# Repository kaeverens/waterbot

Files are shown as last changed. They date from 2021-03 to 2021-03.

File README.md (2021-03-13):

# waterbot
a robot for watering plants

I don't know much about gardening, and I am not attentive enough to stick to a watering regime, so this is a project to do it for me.

The idea is that you place the plants you want to water in a line along a track. A small robot then travels along that track, watering each plant.

IMAGE ALT TEXT (http://www.youtube.com/watch?v=uN9o2ADvFOk "first successful watering - click to see the video")

There is a much larger idea behind all of this, but I'll get to that over time. The short-term goal is that plants should each receive a prescribed amount of water every day.

## How to build

these instructions are not yet complete. I'm filling them in as I rebuild things.

1. build a track, using documentation in the "track" directory.
2. build a bot, using documentation in the "bot" directory.
3. connect a pi to the track port, and install the server (to be written)

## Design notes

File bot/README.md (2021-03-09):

There are 3 versions of the bot

v2 is the current version.

v1 was the prototype.

v3 is the next version.

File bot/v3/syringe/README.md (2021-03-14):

The syringe layer can hold up to 6ml of water and push it out on request. It is controlled through i2c.



power usage estimate is 240mA for the 28BYJ-48 motor, and 10mA for the Arduino.

* when the motor is enabled: 1.25W
* when the motor is disabled: 0.05W

the 28BYJ-48 motor has 2038 steps per revolution. the gear reduction from the motor to the syringe-pushing rack is 1/11 * 14/8, and has teeth that are 3.142mm apart, so one step of the motor drives it 0.00969mm, or 0.01mm rounded.

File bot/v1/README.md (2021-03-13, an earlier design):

these files are of the original prototype of the waterbot.

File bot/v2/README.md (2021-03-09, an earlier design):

the bot is made of three separate layers

the bottom layer is the Transport layer. this layer has a motor and wheels, and has switches to identify when the bot hits a track end, or when it passes a marker on the track to identify where the pots are.

the middle layer is for power and control. this layer has an embedded arduino, battery, and battery charger, and it controls the robot.

the top layer is the syringe layer. this layer is used to pick up and drop off water.

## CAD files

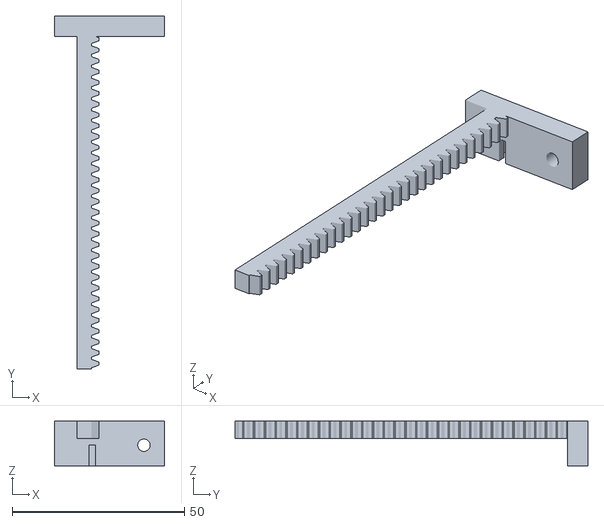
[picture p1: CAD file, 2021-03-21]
bot/v3/syringe/syringe-rack.stl
32.0 x 102.6 x 13.0

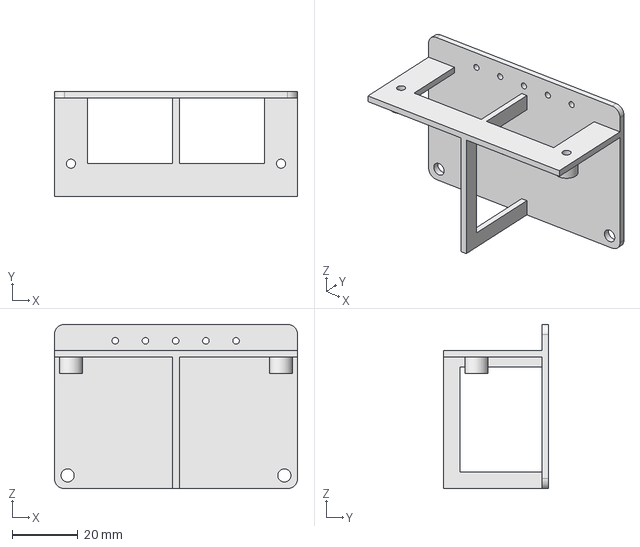
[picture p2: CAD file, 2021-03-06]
dock/dock-wall.FCStd
74.0 x 32.0 x 50.0 mm

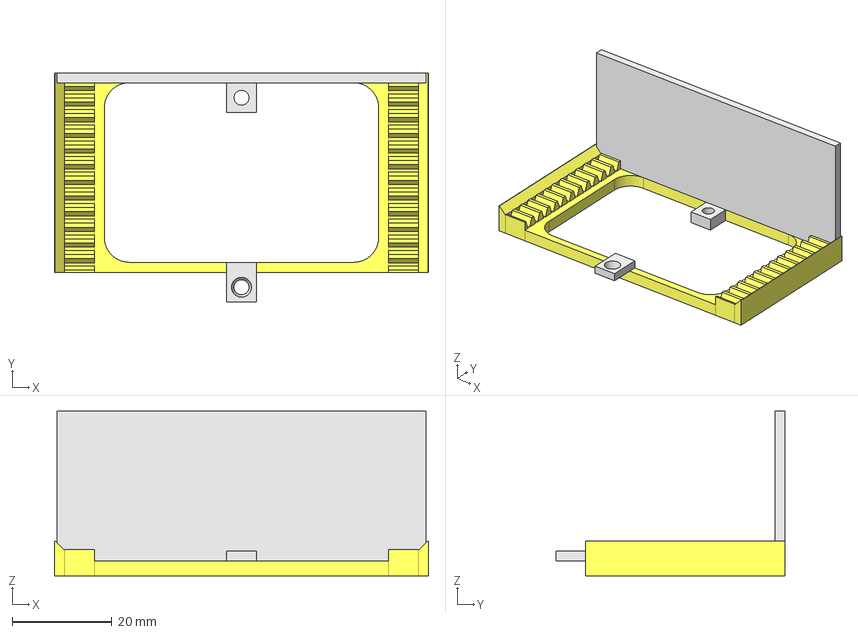
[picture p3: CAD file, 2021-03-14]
tracks/track-end-piece.FCStd
75.0 x 46.0 x 33.0 mm
track

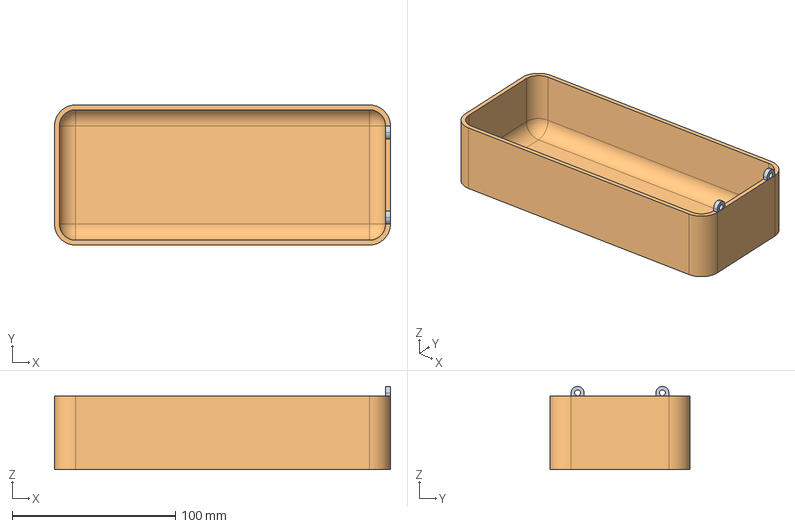
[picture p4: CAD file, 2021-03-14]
trough/trough.FCStd
206.0 x 86.0 x 51.0 mm

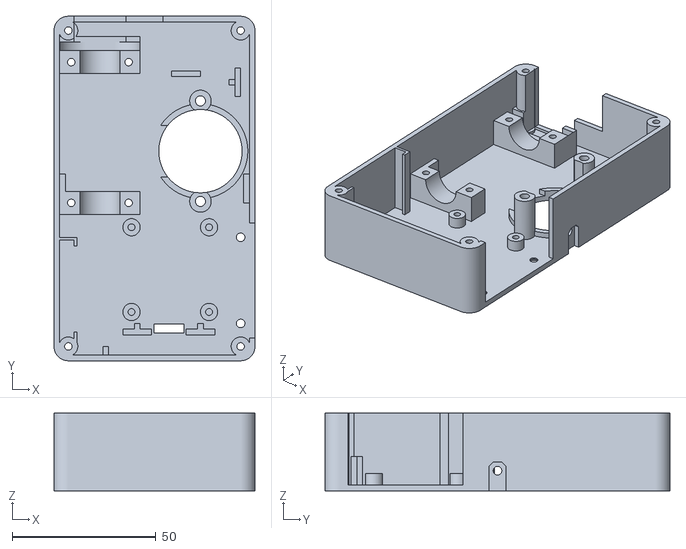
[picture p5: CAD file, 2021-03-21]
bot/v3/syringe/syringe-bottom.stl
70.0 x 120.0 x 27.0

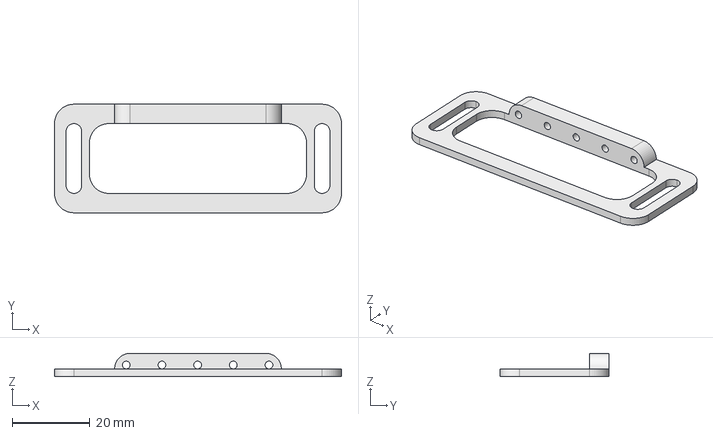
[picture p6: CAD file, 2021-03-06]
dock/dock-pogopin-slider.FCStd
74.0 x 28.0 x 6.00 mm

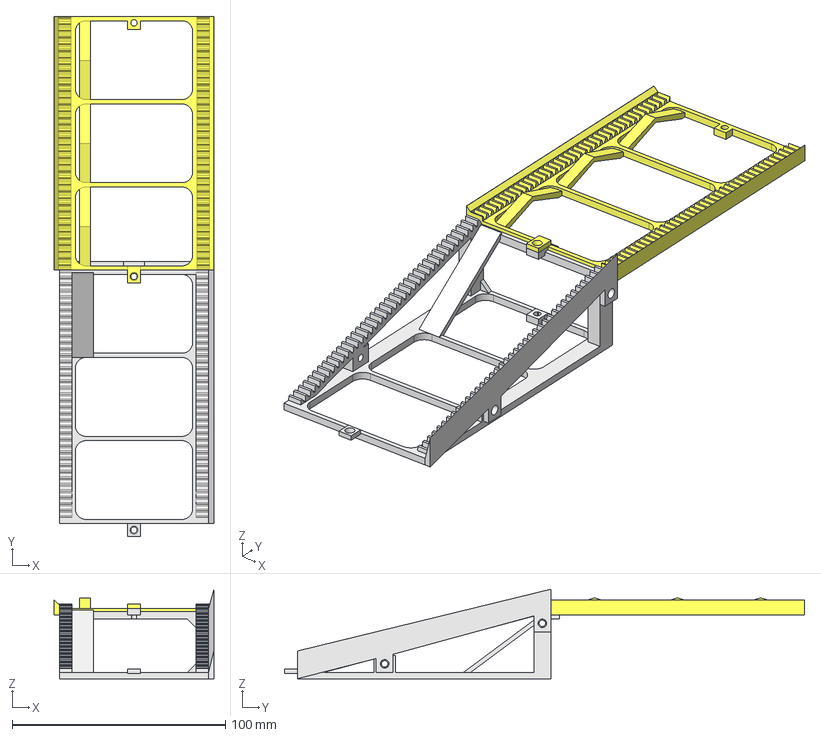
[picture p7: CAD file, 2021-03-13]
tracks/track-riser-30mm.FCStd
75.0 x 244.0 x 42.0 mm
example attached track
3cm riser

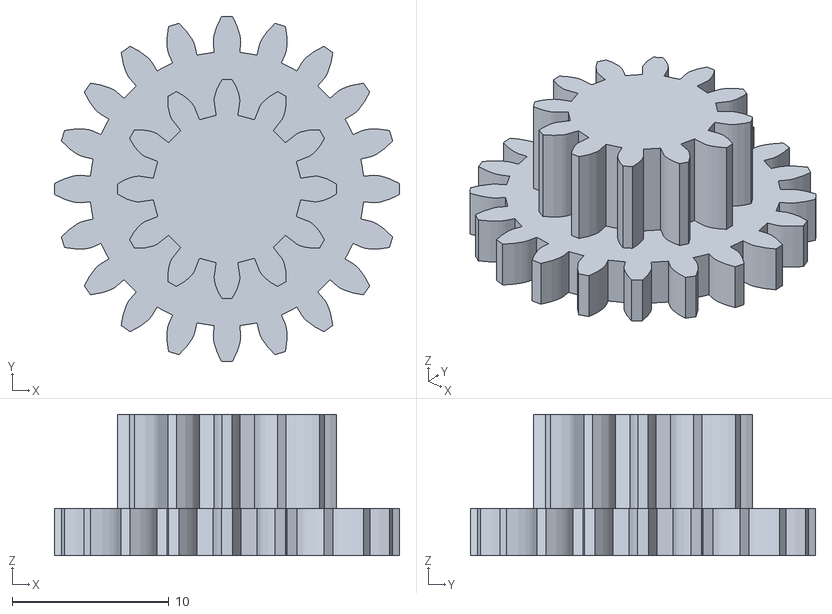
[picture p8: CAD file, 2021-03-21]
bot/v3/syringe/syringe-transmission_gear.stl
22.0 x 22.0 x 9.00

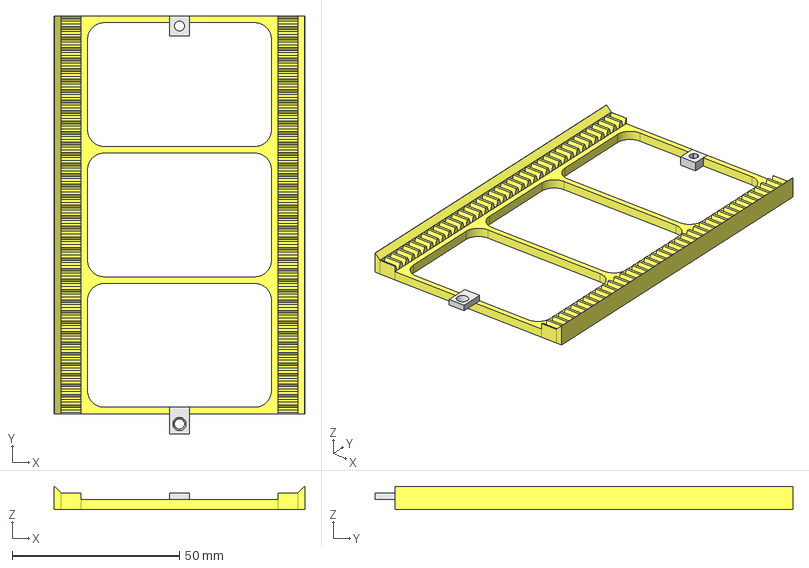
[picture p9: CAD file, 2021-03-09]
tracks/track-120.FCStd
75.0 x 125.0 x 7.00 mm
track

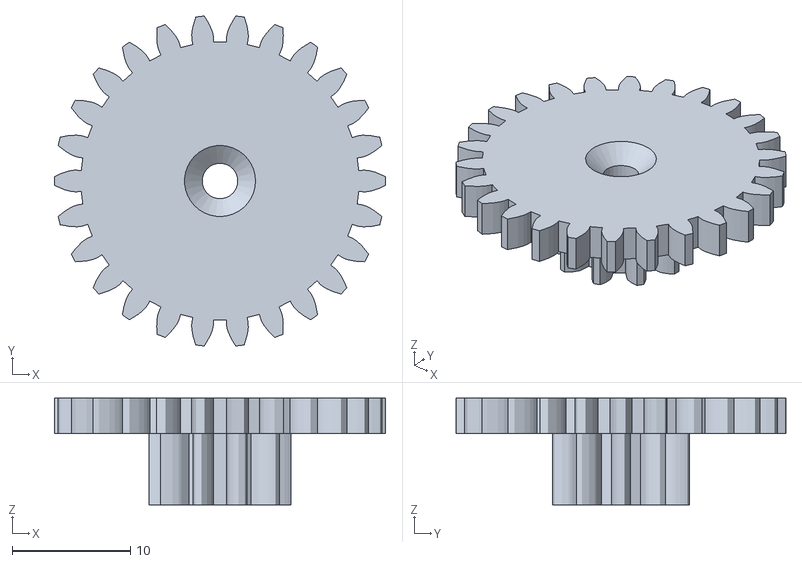
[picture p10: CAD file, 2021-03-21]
bot/v3/syringe/syringe-rack_gear.stl
28.0 x 27.9 x 9.00

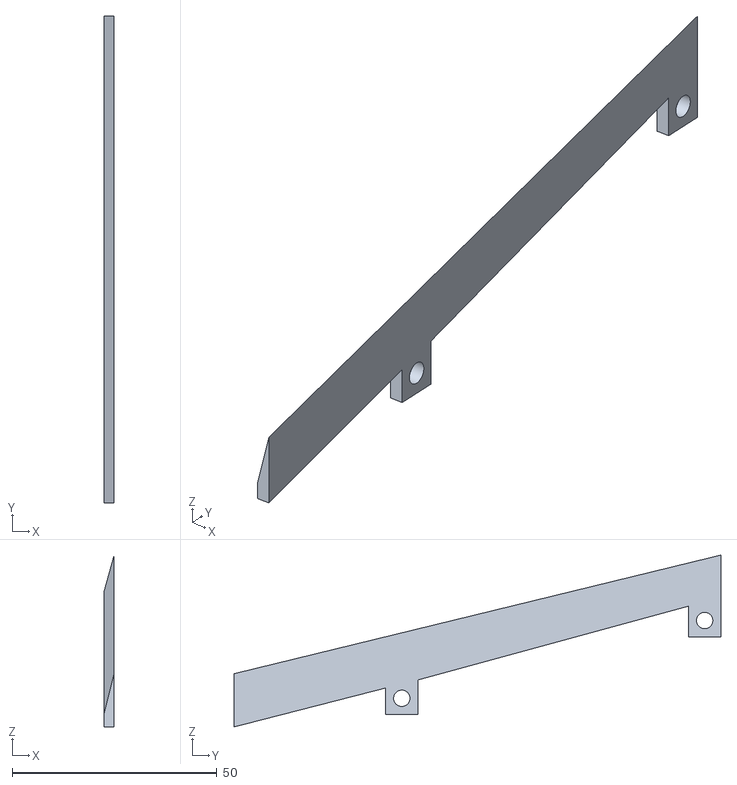
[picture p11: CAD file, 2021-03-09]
tracks/track-riser-30mm-rail.stl
2.50 x 119.0 x 42.0

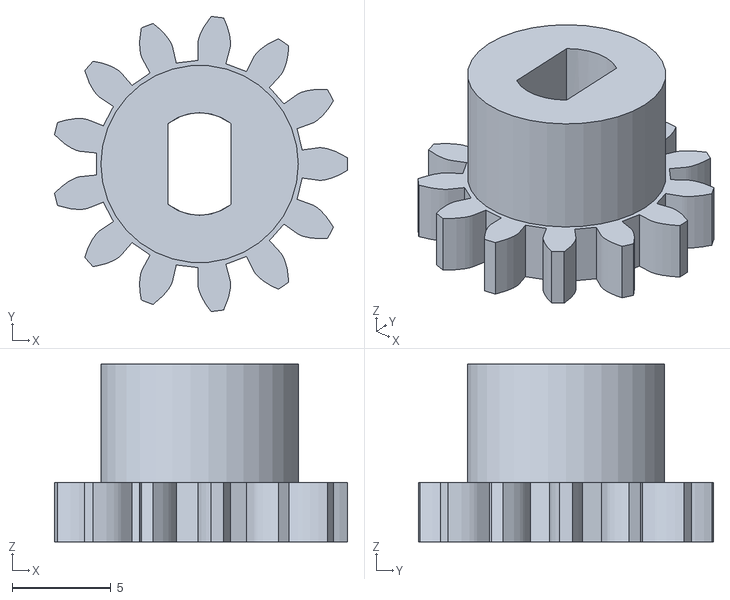
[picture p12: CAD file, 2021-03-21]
bot/v3/syringe/syringe-driver_gear.stl
14.8 x 15.0 x 9.00

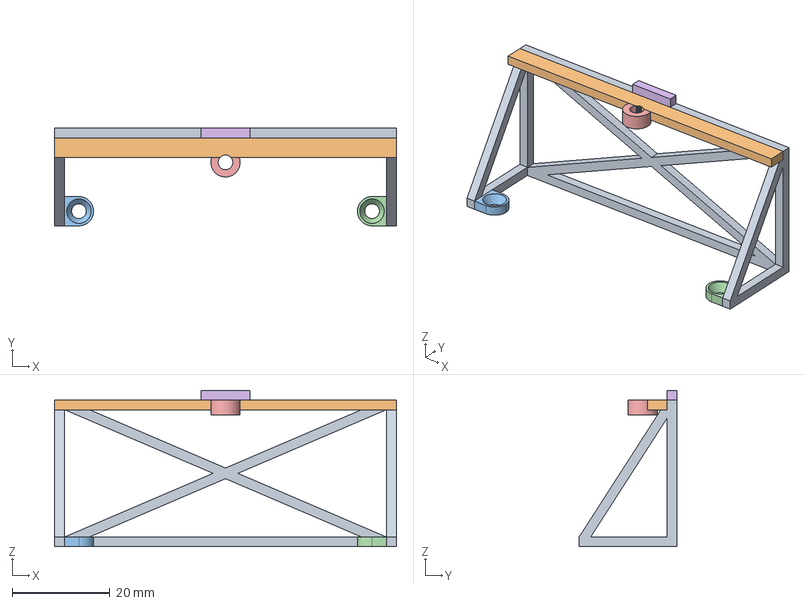
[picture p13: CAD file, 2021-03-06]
tracks/track-truss-30mm.FCStd
70.0 x 20.0 x 32.0 mm

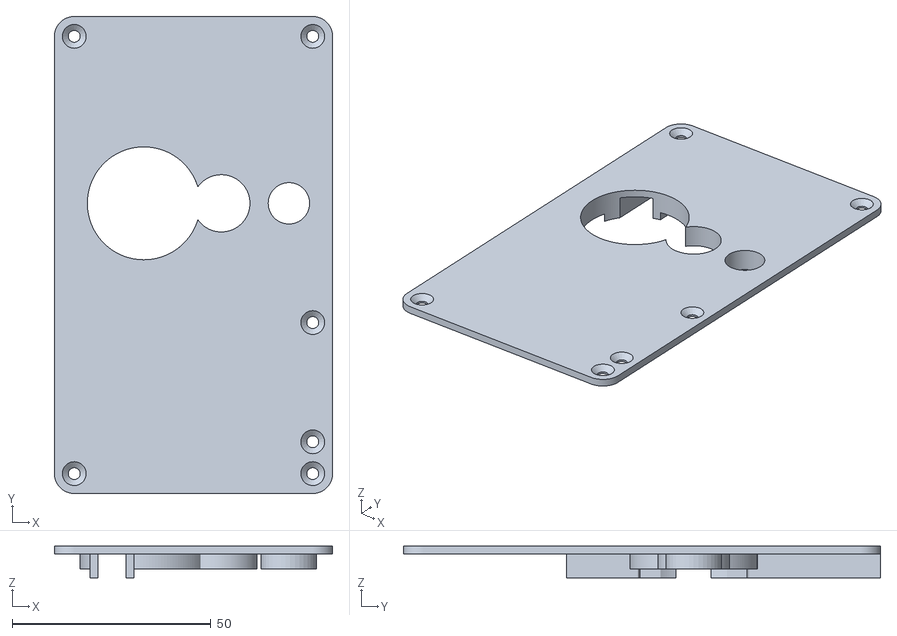
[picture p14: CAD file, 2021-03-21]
bot/v3/syringe/syringe-top.stl
70.0 x 120.0 x 8.00

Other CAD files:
tracks/track-dock.FCStd
bot/v3/syringe/syringe-barrel_strap.stl
tracks/track-120mm.stl
bot/v3/syringe/syringe.FCStd
bot/v1/altogether.FCStd
bot/v1/base-body.FCStd
bot/v1/body-syringe.FCStd
bot/v1/control-boards.FCStd
bot/v1/layer-bumper.FCStd
bot/v1/layer-template.FCStd
bot/v1/motor-axle.FCStd
bot/v1/motor-gear.FCStd
bot/v1/power-block.FCStd
bot/v1/shuttle-top.FCStd
bot/v1/side-switch.FCStd
bot/v1/syringe-mount.FCStd
bot/v1/transmission-gear.FCStd
bot/v1/waterbot.FCStd
bot/v1/wheel-gear.FCStd
bot/v1/wheel.FCStd
bot/v2/power/base.FCStd
bot/v2/power/bot-power-base.stl
bot/v2/syringe/bot-syringe-arm.FCStd
bot/v2/syringe/bot-syringe-arm.stl
bot/v2/syringe/bot-syringe-base.FCStd
bot/v2/syringe/bot-syringe-base.stl
bot/v2/syringe/bot-syringe-mount_body.FCStd
bot/v2/syringe/bot-syringe-mount_body.stl
bot/v2/syringe/bot-syringe-mounts-back.stl
bot/v2/syringe/bot-syringe-mounts-front.stl
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

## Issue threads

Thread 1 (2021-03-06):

syringe arm too long

kaeverens, 2021-03-06:
the syringe arm, when fully extended, pokes out the far side of the robot.

try redesigning the syring holder so the microswitch detects the actual syringe's plunger, not the toothed arm

kaeverens, 2021-03-06:
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

kaeverens, 2021-03-09:
a full redesign of the syringe layer will solve this issue and some others. I'll try redesign it so it's flat, with a tube leading from the end of the syringe out to the side. the tube position should be adjustable.

kaeverens, 2021-03-13:
redesign is well under way.

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

I'm designing this one to work through i2c as the first v3 layer. it won't be compatible with the v2 bot.

kaeverens, 2021-03-14:
closing this, as a rebuild to v3 will solve it. also, I simply moved the track away from the wall, so it's no longer a problem anyway

Closed 2021-03-14.

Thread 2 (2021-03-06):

bottom microswitch gets caught on track joists

kaeverens, 2021-03-06:
the lever of the microswitch dangles too low and gets caught.

two possible solutions

1. remove the lever and hopefully the switch itself can slide over the track lumps
2. redesign tracks so they have a smooth track for the microswitch to roll on where currently it's just a hole

kaeverens, 2021-03-06:
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

kaeverens, 2021-03-06:
simplest solution is the track one.

kaeverens, 2021-03-06:
another possible temporary solution - add some weight to the front of the bot.

more long-term solutions:

1. reduce height of bot in total so centre of balance is lower
2. invert the syringe mechanism so the motor is closer to the centre of the bot horizontally and vertically

I think solution 2 here is the right one.

solution 1 can be worked on when next redesigning the transport layer

kaeverens, 2021-03-06:
after further thinking, there are two further causes

1. the bottom switch is in the exact middle between the two wheel axles. this means the switch can be closer to the track sometimes when the wheels are on a gradient. so another possible long-term solution is to redesign the motor chassis so the switch is directly below an axle.
2. microswitch levers can be loose, so may droop down away from the button. a mitigation for this might be to somehow block the lever from coming away from the button.

solution 1 will definitely fix the problem. solution 2 will not, but may be necessary to solve other potential issues.

kaeverens, 2021-03-06:
I've redesigned the riser track to get rid of the centre joists.

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

the switch will still catch on the top joist, though

kaeverens, 2021-03-06:
ok - and a little mitigation until I can redesign the vehicle layer...

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

I'll print this one out and try it

kaeverens, 2021-03-07:
the ramp works. I needed to shave a little off the neighbouring track to make it smooth, so the ramp needs to be raised a little to cover that in future (done)

Closed 2021-03-07.

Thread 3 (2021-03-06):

track trusses don't give enough support

kaeverens, 2021-03-06:
the trusses are designed to have 2mm tops from one side to the other, but of just one track. the truss needs to support both the track it is screwed to, and the track just next to it.

solution: redesign truss to be at least 4mm across on top, with screw hole moved in accordingly. also, add a "lip" so the other track (the currently non-supported one) is held tighter to the screwed track

kaeverens, 2021-03-06:
redsigned as suggested.

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

also, removed the bottom middle screw hole because it was in a tricky position to use.

redesigned the screw holes of the other bottom ones so they use conical holes.

Closed 2021-03-06.

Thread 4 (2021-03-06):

bot topples if approaching a gradient at speed

kaeverens, 2021-03-06:
because the bot is top-heavy, the centre of balance is high, so raising the front wheels too quickly can cause it to topple.

possible solution: attach a t-shaped hook to the bot which hangs between the wheens. it can be hooked into a channel on the riser track to help stop the bot from toppling

kaeverens, 2021-03-07:
fixed by slowing down motors by using pulses of 20ms on, 20ms off, and by work done in #2

Closed 2021-03-07.

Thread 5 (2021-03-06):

can't adjust speed of motors

kaeverens, 2021-03-06:
the motor controller is either fully on, or fully off, so the bot runs along at full speed, or doesn't move.

I tried using PWM to simulate speed control, but that just ends up with either jerky movement, or a buzzing motor and no movement.

I think in the case of the latter, the frequency is too high, and the motor doesn't have a chance in the power phase to move to another magnet before the power-off phase is reached and it jerks back

Closed 2021-03-07.

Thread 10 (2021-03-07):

create port computer program

kaeverens, 2021-03-07:
the robot receives instructions from the port computer (a Raspberry Pi). at the moment, I do this by logging into the Pi using VNC, and using the Arduino IDE to talk to the robot through the serial monitor.

my plan is to create a node.js server that talks to a database (sqlite? mysql? plain text?) and knows how much each plant needs to be watered each day. then each day, it will get the robot to do the watering.

there will be a lot more to add into this afterwards, but the above is the minimum.

kaeverens, 2021-03-14:
the basics of this are now written.

Closed 2021-03-14.

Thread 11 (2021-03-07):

only fully empty and refill syringe when needed

kaeverens, 2021-03-07:
at the moment, we empty and refill the syringe every time the robot returns to base.

this is a waste of time if we only used a little water and there is still enough left in the syringe to do the next mission.

the robot should be changed so that

1. it empties/refills when the robot is booted.
2. it records how much water is in the syringe after each action
3. the next empty/refill is done only if a mission would reduce the syringe to below 0ml

kaeverens, 2021-03-09:
done!

Closed 2021-03-09.

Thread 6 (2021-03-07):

riser track doesn't support neighbouring track

kaeverens, 2021-03-07:
the riser track's 30mm end connects to its neighbouring track using a screw, but that is all. the rest of the track floats next to the riser, which can lead to dipping of the track sides and possibly other issues

kaeverens, 2021-03-07:
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

kaeverens, 2021-03-07:
this should do it. printing out now.

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

Closed 2021-03-07.

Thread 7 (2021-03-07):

switch to i2c

kaeverens, 2021-03-07:
the wiring for the robot is a little bit crazy because I'm using one gpio port for almost everything that needs to be controlled.

the transport layer alone needs 7 wires

1. vcc
2. ground
3. motorA1
4. motorA2
5. switch front
6. switch back
7. switch bottom

this could be reduced to simply 4 wires per layer if each layer had its own arduino that was controlled by i2c.

and we would not need to use wires at all, really - we could use 4-pin headers to connect each layer to the one below or above it. or 7-pin if we want to be able to reprogram the contained arduino

this is a big project which would involve rebuilding the robot entirely, but it would end up better-looking and easier to work with.

kaeverens, 2021-03-13:
5 wires. we need two VCCs - one for motor, one for logic.

kaeverens, 2021-03-14:
new issues created to carry this forward. this can be closed now

Closed 2021-03-14.

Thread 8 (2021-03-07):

change method used to join layers together

kaeverens, 2021-03-07:
right now, four bolts are used in the corners of the robot to join each layer together.

removing the bolts takes time, and once removed, all layers are separate.

we might sometimes want to take out just one layer and not have the others removed.

a better solution than bolts might be to add [butterfly splines](https://www.google.com/search?q=butterfly+spline) (a woodworking trick) to the sides of the layers, with a screw hole in the top end of each spline to hold it in place. the bottom end would be held in place naturally by the shape of the spline.

removing a layer then just involves removing the splines holding that layer in.

kaeverens, 2021-03-14:
I'm using a simple inset with a bolt hole. I'll use a triangle shape on the bottom layer.

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

Closed 2021-03-14.

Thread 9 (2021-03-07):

connection to port is not solid

kaeverens, 2021-03-07:
the port connection is currently handled using pogo-pins on the port side and bolts on the robot side. a solid connection good enough for serial port communication relies on the robot pressing firmly enough that it forms contact with all pins.

this does not always happen. sometimes the robot will bounce off the port wall. sometimes the pressure of the pins and front switch of the robot will push it away enough that at least one pin disconnects.

kaeverens, 2021-03-07:
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

kaeverens, 2021-03-07:
a possible long-term solution is that we reduce the connection to just VCC and Ground, and use radio or bluetooth communication instead of serial so we don't need so many pins.

another possible solution is that the transport layer will have a "hook" that connects to the port wall when it is close enough, and a solenoid to disconnect that hook when the robot needs to drive off. that's actually probably the simplest solution, I think

kaeverens, 2021-03-09:
I looked into bluetooth - it's apparently possible to program n arduino remotely using a HCL-05 bluetooth module.

I wonder is it possible to then also use that same module for communication, or is it stuck as a remote programmer once set up?

kaeverens, 2021-03-14:
suggestion from here: https://robotics.stackexchange.com/questions/21899/solid-communication-methods-for-a-docking-robot

add two outer pins that are shorted. the robot butts against the pins as normal, and treats those outer pins as a switch. if the switch is closed, then the connection is solid. otherwise, it retries the connection.

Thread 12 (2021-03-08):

add ability for syringe to be dipped into water

kaeverens, 2021-03-08:
the current bot's syringe is fixed in place, so the bot needs to drive down an incline to dip the syringe into a container of water.

this causes a load of problems related to that incline.

when rebuilding the syringe layer for v3, add the ability to dip the syringe end down into the water, so the robot can stay on a flat track and avoid those issues.

kaeverens, 2021-03-14:
I've solved the incline problems. I'll leave this for some other time

Closed 2021-03-14.

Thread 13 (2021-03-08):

increase height of side-rails on riser track.

kaeverens, 2021-03-08:
the bot has slipped out of the track a few times while on the riser track.

to fix this, the riser track should be adjusted so its side-rails are higher.

maybe make the side-rails detachable so if a new one is needed, the entire thing doesn't need to be reprinted

kaeverens, 2021-03-08:
the current design

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

I'll work to remove the rails from the side and create new rails that are smoother and higher above the track

Closed 2021-03-09.

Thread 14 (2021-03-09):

design a water trough

kaeverens, 2021-03-09:
currently using a tray I got when I bought a curry+chips from the local Chinese takeaway.

design a water trough that can hold water up to a height of at least 40mm.

top area should be large enough that when the syringe is drawing water, it doesn't lower to water height too much.

design and install a float so the depth of water can be monitored. we might link this to an external pump at some time to automate topping-up of water.

kaeverens, 2021-03-14:
minimum 40mm height, 40mm width, 200mm length.

probably have a 5mm lip to stop splashes.

80mm width will increase surface area so it takes longer to lower the level. also gives 40mm space for a float.

kaeverens, 2021-03-14:
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

I put two bolt holes on the end so I can design and attach a float and its electronics

Closed 2021-03-14.

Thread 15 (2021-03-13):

create a track end

kaeverens, 2021-03-13:
twice during tests, the bot has driven right off the end of the track.

we need an end-piece to block that from happening.

once it's built, we then need to adjust the code of the bot so that if it detects that it has hit that end-piece, then it should return to base, report a failure in the mission, and move onto the next one

kaeverens, 2021-03-14:
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

Closed 2021-03-14.

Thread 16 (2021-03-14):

if back switch is tripped during a drive, cancel the current mission

kaeverens, 2021-03-14:
if the bot's back switch is tripped, then that means the bot has driven too far and has hit the track end-piece.

if that happens, cancel the current mission and return to base

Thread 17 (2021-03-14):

add a float to the water trough

kaeverens, 2021-03-14:
a float should be added to the water trough to detect when its level is low.

the float's lever should trigger a microswitch when the level is too low, which can be used to turn on a pump to refill the trough

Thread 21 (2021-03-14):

build v3 bot syringe

kaeverens, 2021-03-14:
the syringe layer should be rebuilt to use i2c communication and compact the syringe design down into a flat layer

progress is already made on this:

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

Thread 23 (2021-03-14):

create v3 power layer

kaeverens, 2021-03-14:
create a new power/control layer.

new capabilities:
1. use bluetooth for port communication and programming
2. should use i2c to communicate with other layers
3. should be able to read voltage of battery to estimate charge
4. should recognise when solidly connected to port (using shorted outer pins method)

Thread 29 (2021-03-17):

use JSON serialisation in bot messages

kaeverens, 2021-03-17:
instead of the current messaging where strings are delimited and need to be tightly formatted, just use json. it's easy to extend and more forgiving of mistakes.

kaeverens, 2021-03-17:
this is harder than it seems. ArduiniJson appears to be the only library that people use, but I think that using it is bringing me over the 14336 bytes of program memory that my Arduino is allowing me

kaeverens, 2021-03-17:
ok - can't use JSON. too much memory usage for a tiny machine.

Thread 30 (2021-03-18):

increase power to syringe rack

kaeverens, 2021-03-18:
the v2 bot is having trouble opening the syringe because the rack is too far from the centre axis of the syringe's plunger, causing the rack to flex when force is applied, which then causes it to fail to transfer that force to the plunger itself.

the red line shows where the rack *should* be

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

kaeverens, 2021-03-18:
I'm solving the flex problem in v3 by putting the rack much closer to the plunger's central axis

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

I need to adjust the cogs so the power is increased as much as possible when pushing the rack

kaeverens, 2021-03-18:
v2 gear ratio calculation.

drive gear (on the stepper) has 16 teeth.

transmission gear has 32 teeth on large cog, 12 on small.

so 1 turn of the stepper is:
1. 16/32 = 0.5 turns of the transmission gear
2. 0.5*12 = 6 teeth of the rack are moved when one stepper turn is completed

kaeverens, 2021-03-18:
after adjustment, v3 gear calculation is this:

drive gear (on the stepper) has 13 teeth.

transmission gear has 20 and 10 teeth

rack gear has 26 and 10 teeth

so 1 turn of the stepper is:
1. 13/20 = 0.65 turns of the transmission gear
2. 0.65*(10/26) = 0.25 turns of the rack gear
3. 0.25*10 = 2.5 teeth of the rack.

so the transferred force in v3 should be 2.4 times the v2 transferred force.

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

Closed 2021-03-21.

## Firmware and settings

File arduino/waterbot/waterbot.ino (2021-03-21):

#include <Stepper.h>
// { constants
const int stepsPerRevolution = 2048;
const int stepsPerML=stepsPerRevolution/1.7; // negative pushes down
const int A1A = 9;
const int A1B = 8;
const int SYRINGE_LIMIT = 2;
const int BUMPER_FRONT = 4;
const int BUMPER_BACK = 6;
const int BUMPER_BOTTOM = 5;
// }
int state=0; // return to home
float waterML=0;
unsigned long lastSerialReceived=0;

const int INPUT_SIZE=30; // max expected input size

Stepper myStepper = Stepper(stepsPerRevolution, 10, 12, 11, 13);

// the setup function runs once when you press reset or power the board
void setup() {
  Serial.begin(9600);
  
  myStepper.setSpeed(10);
  stepperOff();

  // motors
  pinMode(A1A, OUTPUT);
  pinMode(A1B, OUTPUT);
    
  // syringe
  pinMode(SYRINGE_LIMIT, INPUT_PULLUP);

  // bumpers
  pinMode(BUMPER_FRONT, INPUT_PULLUP);
  pinMode(BUMPER_BACK, INPUT_PULLUP);
  pinMode(BUMPER_BOTTOM, INPUT_PULLUP);
  stepperOff();
}

void loop() {
  switch (state) {
    case 0: // return to home and refill syringe
      returnToHome();
      Serial.println("setState: 2"); // refilling syringe
      emptySyringe();
      syringe(6);
      Serial.println("setState: 3");
      lastSerialReceived=millis();
      state=3; // wait for command
    break;
    case 1: // return to home
      returnToHome();
      lastSerialReceived=millis();
      Serial.println("setState: 3");
      state=3;
    break;
    case 3: // waiting for command
      if (lastSerialReceived+20000<millis()) { // haven't heard from port in 5s. try to reconnect
          motor('R');
          delay(500);
          motor('O');
          state=1; // return to home
      }
      else {
        readCommand();
      }
    break;
  }
}

void syringe(float ml) {
  myStepper.step(stepsPerML * ml);
  waterML+=ml;
  stepperOff();  
}

void readCommand() {
  if (Serial.available() > 0) {
    lastSerialReceived=millis();
    String input=Serial.readString();
    String cmd=getValue(input, ' ', 0);
    String pot=getValue(input, ' ', 1);
    String ml=getValue(input, ' ', 2);
    if (cmd.equals("water")) {
      float fml=ml.toFloat();
      if (fml>waterML) { // not enough water - refill
        emptySyringe();
        syringe(6);
      }
      waterPot(pot.toInt(), ml.toFloat());
    }
    else if (input.equals("ping\n")) {
      Serial.println("pong");
    }
    else {
      Serial.println("unknown command: "+input);
    }
  }
}

void motorDelay(char dir, int msOn, int msOff) {
  motor(dir);
  delay(msOn);
  motor('O');
  delay(msOff);
}

void waterPot(int pot, float ml) {
  int msOn=10;
  int msOff=5;
  for (int i=0;i<pot;++i) {
    if (i) { // control speed after first marker
      msOn=10;
      msOff=10;
      if (pot-i==1) {
        msOff=30;
      }
      if (pot-i==2) {
        msOff=20;
      }
    }
    moveToNextPot(msOn, msOff);
  }
  syringe(ml*-1);
  state=1; // go back to base for more instruction
}

void moveToNextPot(int msOn, int msOff) {
  int val=1;  
  do { // make sure we are clear of the last bump
    motorDelay('R', msOn, msOff);
    val=digitalRead(BUMPER_BOTTOM);
  } while(val);
  do { // move until bottom button clicks
    motorDelay('R', msOn, msOff);
    val=digitalRead(BUMPER_BOTTOM);
  } while(!val);
}

void returnToHome() {
  int val=1;
  if (!digitalRead(BUMPER_FRONT)) { // already home
    Serial.println("setState: 1");
    return;
  }
  do { // move to base at half speed
    motorDelay('L', 20, 20);
    val=digitalRead(BUMPER_FRONT);
  } while(val);
  delay(100);
  do { // try this a few times until it sticks
   do { // move to base again but at slower speed
     motorDelay('L', 20, 40);
   } while(digitalRead(BUMPER_FRONT));
   delay(1000);
  } while(digitalRead(BUMPER_FRONT));
  Serial.println("setState: 1");
}

String getValue(String data, char separator, int index) {
  int found = 0;
  int strIndex[] = { 0, -1 };
  int maxIndex = data.length() - 1;
  for (int i = 0; i <= maxIndex && found <= index; i++) {
    if (data.charAt(i) == separator || i == maxIndex) {
      found++;
      strIndex[0] = strIndex[1] + 1;
      strIndex[1] = (i == maxIndex) ? i+1 : i;
    }
  }
  return found > index ? data.substring(strIndex[0], strIndex[1]) : "";
}

void emptySyringe() {
  int val=1;
  do {
    myStepper.step(-stepsPerML/10);
    val=digitalRead(SYRINGE_LIMIT);
  } while(val);
  waterML=0;
  stepperOff();
}

void motor(char d) {
  if(d =='R'){
    digitalWrite(A1A,LOW);
    digitalWrite(A1B,HIGH); 
  }
  else if (d =='L'){
    digitalWrite(A1A,HIGH);
    digitalWrite(A1B,LOW);    
  }
  else{
    //Robojax.com L9110 Motor Tutorial
    // Turn motor OFF
    digitalWrite(A1A,LOW);
    digitalWrite(A1B,LOW);    
  }
}

void stepperOff() {
  digitalWrite(10,LOW);
  digitalWrite(11,LOW);
  digitalWrite(12,LOW);
  digitalWrite(13,LOW);
}

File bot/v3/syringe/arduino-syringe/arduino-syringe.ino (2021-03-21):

#include <Wire.h>
#include <Stepper.h>
// { constants
const int stepsPerRevolution = 2048;
const int stepsPerML=stepsPerRevolution/1.7; // negative pushes down
const int SYRINGE_LIMIT = 10;
const int STEPPER_IN1 = 4;
const int STEPPER_IN2 = 5;
const int STEPPER_IN3 = 6;
const int STEPPER_IN4 = 7;
// }
float waterML=0;

Stepper myStepper = Stepper(stepsPerRevolution, STEPPER_IN1, STEPPER_IN3, STEPPER_IN2, STEPPER_IN4);

// the setup function runs once when you press reset or power the board
void setup() {
  Serial.begin(9600);
  myStepper.setSpeed(10);
  stepperOff();
  pinMode(SYRINGE_LIMIT, INPUT_PULLUP);
  pinMode(LED_BUILTIN, OUTPUT);
  Serial.println("booted\n");
  Wire.begin(8);
  Wire.onRequest(requestEvent);
  emptySyringe();
}

void loop() {
  delay(100);
}

void requestEvent(int howMany) {
  digitalWrite(LED_BUILTIN, HIGH);
  while(1<Wire.available()) {
    char c=Wire.read();
    Serial.print(c);
  }
  int x=Wire.read();
  Serial.println(x);
  Wire.write('request received');
  delay(500);
  digitalWrite(LED_BUILTIN, LOW);
  delay(500);
}

void syringe(float ml) {
  myStepper.step(stepsPerML * ml);
  waterML+=ml;
  stepperOff();  
}

void emptySyringe() {
  int val=1;
  do {
    myStepper.step(-stepsPerML/10);
    val=digitalRead(SYRINGE_LIMIT);
  } while(val);
  waterML=0;
  stepperOff();
}

void stepperOff() {
  digitalWrite(STEPPER_IN1, LOW);
  digitalWrite(STEPPER_IN2, LOW);
  digitalWrite(STEPPER_IN3, LOW);
  digitalWrite(STEPPER_IN4, LOW);
}

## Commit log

2021-03-06 first post
    [base.FCStd, bot-power-base.stl, bot-syringe-arm.FCStd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]
2021-03-06 add truss to support raised tracks
    [track-120.FCStd, track-truss-30mm.FCStd, track-truss-30mm.stl]
2021-03-06 fixes #3
    [track-truss-30mm.FCStd, track-truss-30mm.stl]
2021-03-07 fixes #2
    [track-riser-30mm.stl]
2021-03-07 fixes #6
    [track-riser-30mm.stl]
2021-03-09 fixes #13
    [track-riser-30mm-rail.stl, track-riser-30mm.stl]
2021-03-09 rearrange to prepare for bot v3
    [altogether.FCStd, base-body.FCStd, base.FCStd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]
2021-03-13 see #1 - redesign syringe layer
    [syringe-barrel_strap.stl, syringe-bottom.stl, syringe-rack.stl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]
2021-03-13 reorganise syringe directory
    [syringe-barrel_strap.stl, syringe-bottom.stl, syringe-rack.stl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]
2021-03-14 fixes #15 and moves STL into the projects where they came from
    [bot-power-base.stl, bot-syringe-arm.stl, bot-syringe-base.stl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]
2021-03-14 fixes #14
    [trough.FCStd, trough.stl]
2021-03-14 fixes #19 - use bot serial connection to send state to browser
    [index.js, waterbot.ino]
2021-03-15 fixes #20 - ability to add plant pots to database
    [index.js]
2021-03-17 fixes #28 - add ability to delete a pot
    [index.js]
2021-03-21 fixes #30 - better gear-ratio - stronger syringe plunger
    [syringe-barrel_strap.stl, syringe-bottom.stl, syringe-driver_gear.stl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]
